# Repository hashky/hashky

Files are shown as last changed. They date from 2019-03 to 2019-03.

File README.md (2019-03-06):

This is the official repo of the Hashky. It contains everything required to construct a Hashky. 

The Hashky is an open source hardware authentication token and cryptocurrency wallet-seed generator.  It is a stand-alone device, host agnostic.   

Detailed instructions are in doc/manual.pdf. 

## LICENSE 
The Shalite library is a cut-down customize/improved fork of spaniakos/Cryptosuite under AGPL-3.0 license. Forked April 2018. 

The SHA204 library is licensed by Apache V2.0 license.

The rest is MIT license as stated in LICENSE.

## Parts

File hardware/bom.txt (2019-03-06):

5x 2 prong SMT tact switches TS-1236
1x atmel atsha204, SOT23 form factor
1x resistor 0805 4.7kohm-10kohm
1x hashky hat board(included in this git)
1x arduino CJMCU-beetle style board.(there is a similar board with a different pinout but same form factor, see manual)

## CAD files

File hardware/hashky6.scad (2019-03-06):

thick = 1;
length = 21.2;
width = 19.5;
height = 8;
slength = 6;
swidth = 7.5;
usb = 12;

/*u clamp thing*/
difference(){
union(){
difference(){
cube([length+2*thick,width+2*thick,height+2*thick]);
translate([ thick,thick,thick]) cube([length,width,height+thick]);
translate([ (length+2*thick-usb)/2,thick,thick]) cube([usb,width+thick,height*0.75]);
translate([0,-thick,thick*4.2]) cube([thick,thick*5,height/3]);
translate([0,width-thick*4,thick*4.2]) cube([thick,thick*6,height/3]);
}
/*translate([ thick,width-swidth+2*thick,height+thick]) cube([slength+thick,swidth,thick]);*/


translate([ length/2+thick,-0,0]) 

difference(){
scale([1.8,0.9,1]) difference(){
cylinder(height+2*thick,6,6);
cylinder(height+2*thick,4,4);
}
translate([-length,0,0])cube([2*length,width,height+2*thick]);

}
}

translate([thick,0,height+thick]) cube([length,thick,height/5]);
translate([length/4-4.7,width/2+2,0]) scale([0.34,0.34,0.34]) linear_extrude(5) rotate([180,0,0]) text("HASHKY",font = "Boulder:style=Bold");
translate([6.17,9.98,0]) cylinder(height+2*thick,1,1);
}

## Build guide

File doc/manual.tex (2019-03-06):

\documentclass{article}
\usepackage{hyperref}
\usepackage{graphicx}
\usepackage[font=small,labelfont=bf]{caption}
\begin{document}

\title{Manual on construction and use of the Hashky}
\author{Hashky \href{mailto:hashkyinfo@gmail.com}{hashkyinfo@gmail.com}}
\maketitle

\begin{abstract}
This document is to provide description, instructions and philosophy of use of the Hashky. 

\end{abstract}

\section{Motivation}

Password strength is the most important element of maintaining effective security practices. A strong password must be far removed from the human lexicon, which is a property that will make it difficult to remember. Compounding this issue is the suggested practice of changing passwords often. Another property of a strong password is raw entropy content, which manifests itself as long length. This makes typing them time consuming and prone to error. All of these factors make strong passwords inconvenient for the average user.

The Hashky is a platform agnostic piece of hardware designed to overcome these problems. It generates and stores secure authentication entropy in an IC which contains a hardware random number generator and a secure EEPROM. The entropy is easily accessed using a small amount of user supplied entropy(a pin code), and presented using USB keyboard emulation.  

The original use case was for situations which requiring passwords with high entropy in situations where software password managers are not available. A prime case is an encrypted volume at boot; or a bios password. As early development progressed, it became apparent that such a device would be useful for the secure generation and storage of seed entropy for cryptocurrency wallets.  

In order to further increase security, the project was open-sourced, so that the code could be audited to avoid the threat of manufacturer or developer perpetrated compromise.  

\section{Features}

The Hashky is capable of generating three different styles of alphanumeric secrets and passwords. The formats are as follows: BIP39 pneumonic seedphrase, generic short alphanumeric password, IOTA wallet seeds. The generic short format is alphanumeric, lower and uppercase, as well as some special characters selected for maximum compatibility. 

The other formats are open standards and should be referenced in their respective white papers \cite{bip39,iota}. The BIP39 seedphrase is supported by many cryptocurrency wallets of various projects as a wallet recovery function.  

\begin{figure}
\centering
 \captionsetup{width=.7\linewidth}

\caption{The Hashky incarnate, components labeled. The indicator LED is between the two boards, and can be witnessed through the gap labeled above. }
\label{fig:key}
\end{figure}

There are five buttons on the Hashky, labeled in Figure ~\ref{fig:key}. Buttons 1-4 are used for both input of user entropy and selection of password format. The fifth button labeled ENTER is used to mark the end of the sequence and initiate input of the password/secret. 

There is a secure element on the board, which is used to generate and securely store the entropy from which passwords are generated. The secure element contains a hardware random number generator and secure EEPROM that is resistant to physical tampering. For more details, refer to official datasheet of the Atmel ATSHA204. 

This device also has the function of the SHA256 hashing algorithm. The device can access the entropy for hashing, but is configured to preclude reading in plain text. This makes copying a configured Hashky impossible without physically compromising the advanced physical security features of the ATSHA204. 

The generic short format uses a set of $70$ characters and is of length $15$. This makes the entropy of this format $\log_2(70^{15})$, roughly $91$ bits. The code can easily be modified to use more characters. Some special characters are excluded in an effort to give maximum compatibility. It can be easily customised to the user's need without significantly changing the firmware.

\section{Features and use}

When buttons 1-4 have been actuated simultaneously, the device's indicator light will illuminate solid for a few seconds. This indicates that new personal entropy has been generated on the ATSHA204 and written to its EEPROM. Now your device contains your own personal unique entropy, and secrets generated are not dependent on any information known to any external entity. This can be done as many times as you like, but beware, there is no way to recover the state of the device after such a reset. The device must be powered up for this to work, so it will not happen in your pocket. 

Now, to generate/access passwords, the user begins by choosing the output format desired. This is done by pressing one of buttons 1-4. The corresponding formats for each button are:

\begin{enumerate}
\item  BIP39 pneumonic seedphrase \cite{bip39}
\item  BIP39 pneumonic seedphrase \cite{bip39}
\item  Generic 15 character alphanumeric and special character password
\item  IOTA wallet seeds \cite{iota}
\end{enumerate}

Following this selection, the user may input an arbitrary length base 4 sequence that can be thought of as a pin code or and address to each secret. The LED indicator will give a response during each actuation. Also buttons can be held down and actuations counted by observing the activity of the indicator LED(to allow reproducibility). After the desired sequence is entered, the ENTER button is pressed to finish the process and type the password into the host through USB keyboard emulation. This also resets the ephemeral state of the device, so that the same output will be achieved if we return to the output format selection step and reproduce the same sequence of button presses.

The default output is BIP39, so if the user simply hits enter without actuating buttons 1-4, a BIP39 output will be produced. 

The pin code itself should be thought of as a password and entropy. The first element of the code selecting the output format. 

\subsection{Philosophy of use}

The Hashky is a novel secure way to generate cryptocurrency wallets. It is very small(in physical size and memory) which makes it a bad candidate to carry malicious code. It is also open source and has a small codebase, so it can be easily audited. It is also fully deniable, as any input(pin code) to the device will produce a valid seed, so it is an excellent means of transportation for valuable seeds. The device also has no radios nor the capability to call home in any capacity. The connection being a purely physical one there is little chance of a MiTM attack, unless the host device is already compromised in some manner. 

In order to compromise a secret generated by the device, one must physically access your particular device and the relevant pin codes to access your secrets/passwords. If the device is stolen or otherwise placed in the attackers control, the key space is reduced but can only be accessed by entering pin codes into the device, unless the secure element is physically compromised in a hardware attack against the secure EEPROM. The pin codes are of arbitrary length, so in theory one may carry/generate a countably infinite number of passwords/wallet seeds with one Hashky.

Important secrets that are non-recoverable must be backed up by the user in a secure manner. It is the user's responsibility to guarantee that they will not be lost. 

The Hashky is only as secure as the device it is plugged into, you are still subject to keyloggers in a compromised host. 

\subsection{Good practices and tips}

\begin{itemize}
\item Use a USB extension cord to avoid damage to host USB ports when actuating tact switches.
\item Functionality on a tablet or phone is possible using an OTG adapter.
\item For extra security in the case that the device is stolen or lost, use a long pin code.
\item To use very long pin codes, hold buttons down and count the number of actuations by observing the LED response.
\item For use cases where the password can not be recovered, back it up by writing it down or printing it out and store it securely.
\item Remember it is only as secure as what you plug it into. This does not protect against keyloggers. 
\end{itemize} 

\section{Construction and initialization}

Physical construction of the Hashky is straight forward. Obtain all components on the bill of materials, including the Hashky "hat" PCB. Complete the PCB with the buttons and secure element. Now solder the hat PCB on top of the CJMCU beetle board with the pins. They will extend vertically, and must be trimmed after soldering. If you wish to use an ISP programmer for the firmware, you must leave them untrimmed until you have uploaded the firmware and tested the functionality. 

Once the Hashky has been physically constructed, the firmware must be uploaded. 

This is a two stage process. The first firmware is programmed to the device with either an ISP programmer or using the USB interface with the arduino bootloader. This firmware is called "init\_SHA". It contains routines which configure the secure element. This is a one-time process. After burning this firmware the device will be configured a few seconds after power-up and confirm this by emulating a USB keyboard and typing a confirmation text. This is very important for security as if the secure element is not properly configured, it will not make use of its secure features. 

In the main firmware "hashky\_firmware" there is a constant used to initialize the hashing process called "chal" on line 2326. It is not necessary, but good practice, to write some of your own entropy into this variable by changing around the hex digits.  Do not change the length of this variable. 

The firmware requires the two libraries in the firmware/libraries folder, so make them available to your arduino environment. 

The version of arduino used was 1.0.5+dfsg2-4. Some newer versions have serious bugs in parsing engine that will manifest in failure to compile the Hashky firmware. 

The main firmware is then written using either the USB interface with the arduino firmware or an ISP programmer. It is recommended to overwrite the arduino bootloader so that the device can not be accidentally reprogrammed during use. After the main firmware is written, the device is ready. 

The option of programming it over the USB interface using the arduino bootloader has been left for convenience and experimentation. 

The device can be re-initialized at any time by holding down keys 1-4 while the device is powered up. Upon success the LED will go solid then blink several times. This means new entropy has been written to the device. Remember this will overwrite any existing entropy so must be done with caution.

\subsection{Bill of materials}
\begin{itemize}
\item 5x 2 prong SMT tact switches TS-1236
\item 1x atmel atsha204, SOT23 form factor
\item 1x resistor 0805 4.7kohm-10kohm
\item 1x hashky hat board(included in this git)
\item 1x arduino CJMCU-beetle style board. Atmel Atmega32u4 or equivalent. Beware, there exists a board in this form factor with a different pinout. \ref{fig:cjmcu}
\end{itemize}

\begin{figure}
\centering
 \captionsetup{width=.7\linewidth}

\caption{An image of the development board from the BOM. CJMCU-beetle, an Atmel Atmega32u4. }
\label{fig:cjmcu}
\end{figure}

\subsection{Troubleshooting}

If the secure element is not properly connected, it will return all 0s, so the outputs for IOTA seeds and standard passwords will be a string of As. The BIP39 output will be similar, an output containing only the word "ambient". 

The 3D printed case is attached by sliding the male USB region of the device into the opening on the side of the case, so that the entire board is diagonal to the bottom of the case. Then the side opposite to the USB is pushed down, snapping the board down into the case. The case is often very difficult to remove non-destructively after this has been done. The case can physically obstruct the insertion of the Hashky into some USB host ports enough to prevent connection of the data lines. This can be remedied with a USB extension cord. 

It is highly advisable to use a USB extension cord. This avoids causing damage as well as a temporary disconnect of the device during actuation of tact switches. This temporary disconnect can power cycle the device, causing a reset of the ephemeral state of the device, which will confound the pin code sequence being entered(but not damage the device or effect the secure element). 

\begin{thebibliography}{99}
\bibitem{bip39} BIP39 \href{https://github.com/bitcoin/bips/blob/master/bip-0039.mediawiki}{https://github.com/bitcoin/bips/blob/master/bip-0039.mediawiki}
\bibitem{iota} IOTA SUPPORT: Creating a new Seed/Wallet  \href{https://iotasupport.com/gui-newseed.shtml}{https://iotasupport.com/gui-newseed.shtml}
\end{thebibliography}

\end{document}

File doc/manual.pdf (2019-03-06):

## Manual on construction and use of the Hashky

Hashky hashkyinfo@gmail.com

March 6, 2019

Abstract
This document is to provide description, instructions and philosophy of use of the Hashky.

## 1 Motivation

Password strength is the most important element of maintaining effective security practices. A strong password must be far removed from the human lexicon, which is a property that will make it difficult to remember. Compounding this issue is the suggested practice of changing passwords often. Another property of a strong password is raw entropy content, which manifests itself as long length. This makes typing them time consuming and prone to error. All of these factors make strong passwords inconvenient for the average user.
The Hashky is a platform agnostic piece of hardware designed to overcome these problems. It generates and stores secure authentication entropy in an IC which contains a hardware random number generator and a secure EEPROM. The entropy is easily accessed using a small amount of user supplied entropy(a pin code), and presented using USB keyboard emulation.
The original use case was for situations which requiring passwords with high entropy in situations where software password managers are not available. A prime case is an encrypted volume at boot; or a bios password. As early development progressed, it became apparent that such a device would be useful for the secure generation and storage of seed entropy for cryptocurrency wallets. In order to further increase security, the project was open-sourced, so that the code could be audited to avoid the threat of manufacturer or developer perpetrated compromise.

## 2 Features

The Hashky is capable of generating three different styles of alphanumeric secrets and passwords. The formats are as follows: BIP39 pneumonic seedphrase, generic short alphanumeric password, IOTA wallet seeds. The generic short format is alphanumeric, lower and uppercase, as well as some special characters selected for maximum compatibility.

1

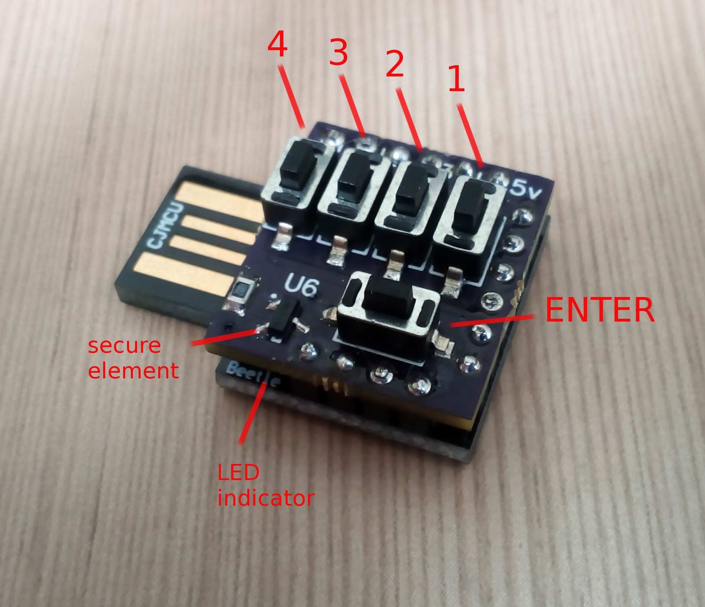
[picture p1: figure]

Figure 1: The Hashky incarnate, components labeled. The indicator LED is between the two boards, and can be witnessed through the gap labeled above.

The other formats are open standards and should be referenced in their respective white papers [1, 2]. The BIP39 seedphrase is supported by many cryptocurrency wallets of various projects as a wallet recovery function.
There are five buttons on the Hashky, labeled in Figure 1. Buttons 1-4 are used for both input of user entropy and selection of password format. The fifth button labeled ENTER is used to mark the end of the sequence and initiate input of the password/secret.
There is a secure element on the board, which is used to generate and securely store the entropy from which passwords are generated. The secure element contains a hardware random number generator and secure EEPROM that is resistant to physical tampering. For more details, refer to official datasheet of the Atmel ATSHA204.
This device also has the function of the SHA256 hashing algorithm. The device can access the entropy for hashing, but is configured to preclude reading in plain text. This makes copying a configured Hashky impossible without physically compromising the advanced physical security features of the ATSHA204. The generic short format uses a set of 70 characters and is of length 15. This makes the entropy of this format log2

(70¹⁵), roughly 91 bits. The code can easily be modified to use more characters. Some special characters are excluded in an effort to give maximum compatibility. It can be easily customised to the user’s need without significantly changing the firmware.

## 3 Features and use

When buttons 1-4 have been actuated simultaneously, the device’s indicator light will illuminate solid for a few seconds. This indicates that new personal entropy has been generated on the ATSHA204 and written to its EEPROM. Now

2

your device contains your own personal unique entropy, and secrets generated are not dependent on any information known to any external entity. This can be done as many times as you like, but beware, there is no way to recover the state of the device after such a reset. The device must be powered up for this to work, so it will not happen in your pocket.
Now, to generate/access passwords, the user begins by choosing the output format desired. This is done by pressing one of buttons 1-4. The corresponding formats for each button are:

### 1. BIP39 pneumonic seedphrase [1]

### 2. BIP39 pneumonic seedphrase [1]

### 3. Generic 15 character alphanumeric and special character password

### 4. IOTA wallet seeds [2]

Following this selection, the user may input an arbitrary length base 4 sequence that can be thought of as a pin code or and address to each secret. The LED indicator will give a response during each actuation. Also buttons can be held down and actuations counted by observing the activity of the indicator LED(to allow reproducibility). After the desired sequence is entered, the ENTER button is pressed to finish the process and type the password into the host through USB keyboard emulation. This also resets the ephemeral state of the device, so that the same output will be achieved if we return to the output format selection step and reproduce the same sequence of button presses.
The default output is BIP39, so if the user simply hits enter without actuating buttons 1-4, a BIP39 output will be produced.
The pin code itself should be thought of as a password and entropy. The first element of the code selecting the output format.

### 3.1 Philosophy of use

The Hashky is a novel secure way to generate cryptocurrency wallets. It is very small(in physical size and memory) which makes it a bad candidate to carry malicious code. It is also open source and has a small codebase, so it can be easily audited. It is also fully deniable, as any input(pin code) to the device will produce a valid seed, so it is an excellent means of transportation for valuable seeds. The device also has no radios nor the capability to call home in any capacity. The connection being a purely physical one there is little chance of a MiTM attack, unless the host device is already compromised in some manner. In order to compromise a secret generated by the device, one must physically access your particular device and the relevant pin codes to access your secrets/passwords. If the device is stolen or otherwise placed in the attackers control, the key space is reduced but can only be accessed by entering pin codes into the device, unless the secure element is physically compromised in a hardware attack against the secure EEPROM. The pin codes are of arbitrary

3

length, so in theory one may carry/generate a countably infinite number of passwords/wallet seeds with one Hashky.
Important secrets that are non-recoverable must be backed up by the user in a secure manner. It is the user’s responsibility to guarantee that they will not be lost.
The Hashky is only as secure as the device it is plugged into, you are still subject to keyloggers in a compromised host.

### 3.2 Good practices and tips

- Use a USB extension cord to avoid damage to host USB ports when actuating tact switches.
- Functionality on a tablet or phone is possible using an OTG adapter.
- For extra security in the case that the device is stolen or lost, use a long pin code.
- To use very long pin codes, hold buttons down and count the number of actuations by observing the LED response.
- For use cases where the password can not be recovered, back it up by writing it down or printing it out and store it securely.
- Remember it is only as secure as what you plug it into. This does not protect against keyloggers.

## 4 Construction and initialization

Physical construction of the Hashky is straight forward. Obtain all components on the bill of materials, including the Hashky ”hat” PCB. Complete the PCB with the buttons and secure element. Now solder the hat PCB on top of the CJMCU beetle board with the pins. They will extend vertically, and must be trimmed after soldering. If you wish to use an ISP programmer for the firmware, you must leave them untrimmed until you have uploaded the firmware and tested the functionality.
Once the Hashky has been physically constructed, the firmware must be uploaded.
This is a two stage process. The first firmware is programmed to the device with either an ISP programmer or using the USB interface with the arduino bootloader. This firmware is called ”init SHA”. It contains routines which configure the secure element. This is a one-time process. After burning this firmware the device will be configured a few seconds after power-up and confirm this by emulating a USB keyboard and typing a confirmation text. This is very important for security as if the secure element is not properly configured, it will not make use of its secure features.

4

In the main firmware ”hashky firmware” there is a constant used to initialize the hashing process called ”chal” on line 2326. It is not necessary, but good practice, to write some of your own entropy into this variable by changing around the hex digits. Do not change the length of this variable.
The firmware requires the two libraries in the firmware/libraries folder, so make them available to your arduino environment.
The version of arduino used was 1.0.5+dfsg2-4. Some newer versions have serious bugs in parsing engine that will manifest in failure to compile the Hashky firmware.
The main firmware is then written using either the USB interface with the arduino firmware or an ISP programmer. It is recommended to overwrite the arduino bootloader so that the device can not be accidentally reprogrammed during use. After the main firmware is written, the device is ready.
The option of programming it over the USB interface using the arduino bootloader has been left for convenience and experimentation.
The device can be re-initialized at any time by holding down keys 1-4 while the device is powered up. Upon success the LED will go solid then blink several times. This means new entropy has been written to the device. Remember this will overwrite any existing entropy so must be done with caution.

### 4.1 Bill of materials

- 5x 2 prong SMT tact switches TS-1236
- 1x atmel atsha204, SOT23 form factor
- 1x resistor 0805 4.7kohm-10kohm
- 1x hashky hat board(included in this git)
- 1x arduino CJMCU-beetle style board. Atmel Atmega32u4 or equivalent. Beware, there exists a board in this form factor with a different pinout. 2

### 4.2 Troubleshooting

If the secure element is not properly connected, it will return all 0s, so the outputs for IOTA seeds and standard passwords will be a string of As. The BIP39 output will be similar, an output containing only the word ”ambient”. The 3D printed case is attached by sliding the male USB region of the device into the opening on the side of the case, so that the entire board is diagonal to the bottom of the case. Then the side opposite to the USB is pushed down, snapping the board down into the case. The case is often very difficult to remove non-destructively after this has been done. The case can physically obstruct the insertion of the Hashky into some USB host ports enough to prevent connection of the data lines. This can be remedied with a USB extension cord.
It is highly advisable to use a USB extension cord. This avoids causing damage as well as a temporary disconnect of the device during actuation of tact

5

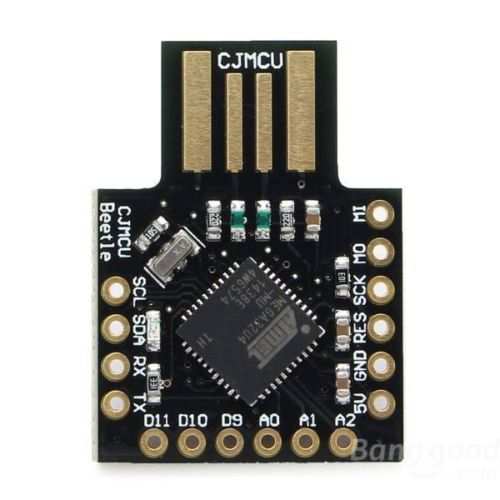
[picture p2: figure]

Figure 2: An image of the development board from the BOM. CJMCU-beetle, an Atmel Atmega32u4.

switches. This temporary disconnect can power cycle the device, causing a reset of the ephemeral state of the device, which will confound the pin code sequence being entered(but not damage the device or effect the secure element).

## References

[1] BIP39 https://github.com/bitcoin/bips/blob/master/bip-0039.mediawiki
[2] IOTA | SUPPORT: | Creating | a | new | Seed/Wallet
https://iotasupport.com/gui-newseed.shtml

6

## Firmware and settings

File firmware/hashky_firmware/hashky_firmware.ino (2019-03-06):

#include "sha256_lite.h" //sha lib for checksum
#include <avr/pgmspace.h>
#include <SHA204SWI.h>
#include <SHA204Definitions.h>

SHA204SWI sha204;

const char string_0[] PROGMEM ="abandon";
const char string_1[] PROGMEM ="ability";
const char string_2[] PROGMEM ="able";
const char string_3[] PROGMEM ="about";
const char string_4[] PROGMEM ="above";
const char string_5[] PROGMEM ="absent";
const char string_6[] PROGMEM ="absorb";
const char string_7[] PROGMEM ="abstract";
const char string_8[] PROGMEM ="absurd";
const char string_9[] PROGMEM ="abuse";
const char string_10[] PROGMEM ="access";
const char string_11[] PROGMEM ="accident";
const char string_12[] PROGMEM ="account";
const char string_13[] PROGMEM ="accuse";
const char string_14[] PROGMEM ="achieve";
const char string_15[] PROGMEM ="acid";
const char string_16[] PROGMEM ="acoustic";
const char string_17[] PROGMEM ="acquire";
const char string_18[] PROGMEM ="across";
const char string_19[] PROGMEM ="act";
const char string_20[] PROGMEM ="action";
const char string_21[] PROGMEM ="actor";
const char string_22[] PROGMEM ="actress";
const char string_23[] PROGMEM ="actual";
const char string_24[] PROGMEM ="adapt";
const char string_25[] PROGMEM ="add";
const char string_26[] PROGMEM ="addict";
const char string_27[] PROGMEM ="address";
const char string_28[] PROGMEM ="adjust";
const char string_29[] PROGMEM ="admit";
const char string_30[] PROGMEM ="adult";
const char string_31[] PROGMEM ="advance";
const char string_32[] PROGMEM ="advice";
const char string_33[] PROGMEM ="aerobic";
const char string_34[] PROGMEM ="affair";
const char string_35[] PROGMEM ="afford";
const char string_36[] PROGMEM ="afraid";
const char string_37[] PROGMEM ="again";
const char string_38[] PROGMEM ="age";
const char string_39[] PROGMEM ="agent";
const char string_40[] PROGMEM ="agree";
const char string_41[] PROGMEM ="ahead";
const char string_42[] PROGMEM ="aim";
const char string_43[] PROGMEM ="air";
const char string_44[] PROGMEM ="airport";
const char string_45[] PROGMEM ="aisle";
const char string_46[] PROGMEM ="alarm";
const char string_47[] PROGMEM ="album";
const char string_48[] PROGMEM ="alcohol";
const char string_49[] PROGMEM ="alert";
const char string_50[] PROGMEM ="alien";
const char string_51[] PROGMEM ="all";
const char string_52[] PROGMEM ="alley";
const char string_53[] PROGMEM ="allow";
const char string_54[] PROGMEM ="almost";
const char string_55[] PROGMEM ="alone";
const char string_56[] PROGMEM ="alpha";
const char string_57[] PROGMEM ="already";
const char string_58[] PROGMEM ="also";
const char string_59[] PROGMEM ="alter";
const char string_60[] PROGMEM ="always";
const char string_61[] PROGMEM ="amateur";
const char string_62[] PROGMEM ="amazing";
const char string_63[] PROGMEM ="among";
const char string_64[] PROGMEM ="amount";
const char string_65[] PROGMEM ="amused";
const char string_66[] PROGMEM ="analyst";
const char string_67[] PROGMEM ="anchor";
const char string_68[] PROGMEM ="ancient";
const char string_69[] PROGMEM ="anger";
const char string_70[] PROGMEM ="angle";
const char string_71[] PROGMEM ="angry";
const char string_72[] PROGMEM ="animal";
const char string_73[] PROGMEM ="ankle";
const char string_74[] PROGMEM ="announce";
const char string_75[] PROGMEM ="annual";
const char string_76[] PROGMEM ="another";
const char string_77[] PROGMEM ="answer";
const char string_78[] PROGMEM ="antenna";
const char string_79[] PROGMEM ="antique";
const char string_80[] PROGMEM ="anxiety";
const char string_81[] PROGMEM ="any";
const char string_82[] PROGMEM ="apart";
const char string_83[] PROGMEM ="apology";
const char string_84[] PROGMEM ="appear";
const char string_85[] PROGMEM ="apple";
const char string_86[] PROGMEM ="approve";
const char string_87[] PROGMEM ="april";
const char string_88[] PROGMEM ="arch";
const char string_89[] PROGMEM ="arctic";
const char string_90[] PROGMEM ="area";
const char string_91[] PROGMEM ="arena";
const char string_92[] PROGMEM ="argue";
const char string_93[] PROGMEM ="arm";
const char string_94[] PROGMEM ="armed";
const char string_95[] PROGMEM ="armor";
const char string_96[] PROGMEM ="army";
const char string_97[] PROGMEM ="around";
const char string_98[] PROGMEM ="arrange";
const char string_99[] PROGMEM ="arrest";
const char string_100[] PROGMEM ="arrive";
const char string_101[] PROGMEM ="arrow";
const char string_102[] PROGMEM ="art";
const char string_103[] PROGMEM ="artefact";
const char string_104[] PROGMEM ="artist";
const char string_105[] PROGMEM ="artwork";
const char string_106[] PROGMEM ="ask";
const char string_107[] PROGMEM ="aspect";
const char string_108[] PROGMEM ="assault";
const char string_109[] PROGMEM ="asset";
const char string_110[] PROGMEM ="assist";
const char string_111[] PROGMEM ="assume";
const char string_112[] PROGMEM ="asthma";
const char string_113[] PROGMEM ="athlete";
const char string_114[] PROGMEM ="atom";
const char string_115[] PROGMEM ="attack";
const char string_116[] PROGMEM ="attend";
const char string_117[] PROGMEM ="attitude";
const char string_118[] PROGMEM ="attract";
const char string_119[] PROGMEM ="auction";
const char string_120[] PROGMEM ="audit";
const char string_121[] PROGMEM ="august";
const char string_122[] PROGMEM ="aunt";
const char string_123[] PROGMEM ="author";
const char string_124[] PROGMEM ="auto";
const char string_125[] PROGMEM ="autumn";
const char string_126[] PROGMEM ="average";
const char string_127[] PROGMEM ="avocado";
const char string_128[] PROGMEM ="avoid";
const char string_129[] PROGMEM ="awake";
const char string_130[] PROGMEM ="aware";
const char string_131[] PROGMEM ="away";
const char string_132[] PROGMEM ="awesome";
const char string_133[] PROGMEM ="awful";
const char string_134[] PROGMEM ="awkward";
const char string_135[] PROGMEM ="axis";
const char string_136[] PROGMEM ="baby";
const char string_137[] PROGMEM ="bachelor";
const char string_138[] PROGMEM ="bacon";
const char string_139[] PROGMEM ="badge";
const char string_140[] PROGMEM ="bag";
const char string_141[] PROGMEM ="balance";
const char string_142[] PROGMEM ="balcony";
const char string_143[] PROGMEM ="ball";
const char string_144[] PROGMEM ="bamboo";
const char string_145[] PROGMEM ="banana";
const char string_146[] PROGMEM ="banner";
const char string_147[] PROGMEM ="bar";
const char string_148[] PROGMEM ="barely";
const char string_149[] PROGMEM ="bargain";
const char string_150[] PROGMEM ="barrel";
const char string_151[] PROGMEM ="base";
const char string_152[] PROGMEM ="basic";
const char string_153[] PROGMEM ="basket";
const char string_154[] PROGMEM ="battle";
const char string_155[] PROGMEM ="beach";
const char string_156[] PROGMEM ="bean";
const char string_157[] PROGMEM ="beauty";
const char string_158[] PROGMEM ="because";
const char string_159[] PROGMEM ="become";
const char string_160[] PROGMEM ="beef";
const char string_161[] PROGMEM ="before";
const char string_162[] PROGMEM ="begin";
const char string_163[] PROGMEM ="behave";
const char string_164[] PROGMEM ="behind";
const char string_165[] PROGMEM ="believe";
const char string_166[] PROGMEM ="below";
const char string_167[] PROGMEM ="belt";
const char string_168[] PROGMEM ="bench";
const char string_169[] PROGMEM ="benefit";
const char string_170[] PROGMEM ="best";
const char string_171[] PROGMEM ="betray";
const char string_172[] PROGMEM ="better";
const char string_173[] PROGMEM ="between";
const char string_174[] PROGMEM ="beyond";
const char string_175[] PROGMEM ="bicycle";
const char string_176[] PROGMEM ="bid";
const char string_177[] PROGMEM ="bike";
const char string_178[] PROGMEM ="bind";
const char string_179[] PROGMEM ="biology";
const char string_180[] PROGMEM ="bird";
const char string_181[] PROGMEM ="birth";
const char string_182[] PROGMEM ="bitter";
const char string_183[] PROGMEM ="black";
const char string_184[] PROGMEM ="blade";
const char string_185[] PROGMEM ="blame";
const char string_186[] PROGMEM ="blanket";
const char string_187[] PROGMEM ="blast";
const char string_188[] PROGMEM ="bleak";
const char string_189[] PROGMEM ="bless";
const char string_190[] PROGMEM ="blind";
const char string_191[] PROGMEM ="blood";
const char string_192[] PROGMEM ="blossom";
const char string_193[] PROGMEM ="blouse";
const char string_194[] PROGMEM ="blue";
const char string_195[] PROGMEM ="blur";
const char string_196[] PROGMEM ="blush";
const char string_197[] PROGMEM ="board";
const char string_198[] PROGMEM ="boat";
const char string_199[] PROGMEM ="body";
const char string_200[] PROGMEM ="boil";
const char string_201[] PROGMEM ="bomb";
const char string_202[] PROGMEM ="bone";
const char string_203[] PROGMEM ="bonus";
const char string_204[] PROGMEM ="book";
const char string_205[] PROGMEM ="boost";
const char string_206[] PROGMEM ="border";
const char string_207[] PROGMEM ="boring";
const char string_208[] PROGMEM ="borrow";
const char string_209[] PROGMEM ="boss";
const char string_210[] PROGMEM ="bottom";
const char string_211[] PROGMEM ="bounce";
const char string_212[] PROGMEM ="box";
const char string_213[] PROGMEM ="boy";
const char string_214[] PROGMEM ="bracket";
const char string_215[] PROGMEM ="brain";
const char string_216[] PROGMEM ="brand";
const char string_217[] PROGMEM ="brass";
const char string_218[] PROGMEM ="brave";
const char string_219[] PROGMEM ="bread";
const char string_220[] PROGMEM ="breeze";
const char string_221[] PROGMEM ="brick";
const char string_222[] PROGMEM ="bridge";
const char string_223[] PROGMEM ="brief";
const char string_224[] PROGMEM ="bright";
const char string_225[] PROGMEM ="bring";
const char string_226[] PROGMEM ="brisk";
const char string_227[] PROGMEM ="broccoli";
const char string_228[] PROGMEM ="broken";
const char string_229[] PROGMEM ="bronze";
const char string_230[] PROGMEM ="broom";
const char string_231[] PROGMEM ="brother";
const char string_232[] PROGMEM ="brown";
const char string_233[] PROGMEM ="brush";
const char string_234[] PROGMEM ="bubble";
const char string_235[] PROGMEM ="buddy";
const char string_236[] PROGMEM ="budget";
const char string_237[] PROGMEM ="buffalo";
const char string_238[] PROGMEM ="build";
const char string_239[] PROGMEM ="bulb";
const char string_240[] PROGMEM ="bulk";
const char string_241[] PROGMEM ="bullet";
const char string_242[] PROGMEM ="bundle";
const char string_243[] PROGMEM ="bunker";
const char string_244[] PROGMEM ="burden";
const char string_245[] PROGMEM ="burger";
const char string_246[] PROGMEM ="burst";
const char string_247[] PROGMEM ="bus";
const char string_248[] PROGMEM ="business";
const char string_249[] PROGMEM ="busy";
const char string_250[] PROGMEM ="butter";
const char string_251[] PROGMEM ="buyer";
const char string_252[] PROGMEM ="buzz";
const char string_253[] PROGMEM ="cabbage";
const char string_254[] PROGMEM ="cabin";
const char string_255[] PROGMEM ="cable";
const char string_256[] PROGMEM ="cactus";
const char string_257[] PROGMEM ="cage";
const char string_258[] PROGMEM ="cake";
const char string_259[] PROGMEM ="call";
const char string_260[] PROGMEM ="calm";
const char string_261[] PROGMEM ="camera";
const char string_262[] PROGMEM ="camp";
const char string_263[] PROGMEM ="can";
const char string_264[] PROGMEM ="canal";
const char string_265[] PROGMEM ="cancel";
const char string_266[] PROGMEM ="candy";
const char string_267[] PROGMEM ="cannon";
const char string_268[] PROGMEM ="canoe";
const char string_269[] PROGMEM ="canvas";
const char string_270[] PROGMEM ="canyon";
const char string_271[] PROGMEM ="capable";
const char string_272[] PROGMEM ="capital";
const char string_273[] PROGMEM ="captain";
const char string_274[] PROGMEM ="car";
const char string_275[] PROGMEM ="carbon";
const char string_276[] PROGMEM ="card";
const char string_277[] PROGMEM ="cargo";
const char string_278[] PROGMEM ="carpet";
const char string_279[] PROGMEM ="carry";
const char string_280[] PROGMEM ="cart";
const char string_281[] PROGMEM ="case";
const char string_282[] PROGMEM ="cash";
const char string_283[] PROGMEM ="casino";
const char string_284[] PROGMEM ="castle";
const char string_285[] PROGMEM ="casual";
const char string_286[] PROGMEM ="cat";
const char string_287[] PROGMEM ="catalog";
const char string_288[] PROGMEM ="catch";
const char string_289[] PROGMEM ="category";
const char string_290[] PROGMEM ="cattle";
const char string_291[] PROGMEM ="caught";
const char string_292[] PROGMEM ="cause";
const char string_293[] PROGMEM ="caution";
const char string_294[] PROGMEM ="cave";
const char string_295[] PROGMEM ="ceiling";
const char string_296[] PROGMEM ="celery";
const char string_297[] PROGMEM ="cement";
const char string_298[] PROGMEM ="census";
const char string_299[] PROGMEM ="century";
const char string_300[] PROGMEM ="cereal";
const char string_301[] PROGMEM ="certain";
const char string_302[] PROGMEM ="chair";
const char string_303[] PROGMEM ="chalk";
const char string_304[] PROGMEM ="champion";
const char string_305[] PROGMEM ="change";
const char string_306[] PROGMEM ="chaos";
const char string_307[] PROGMEM ="chapter";
const char string_308[] PROGMEM ="charge";
const char string_309[] PROGMEM ="chase";
const char string_310[] PROGMEM ="chat";
const char string_311[] PROGMEM ="cheap";
const char string_312[] PROGMEM ="check";
const char string_313[] PROGMEM ="cheese";
const char string_314[] PROGMEM ="chef";
const char string_315[] PROGMEM ="cherry";
const char string_316[] PROGMEM ="chest";
const char string_317[] PROGMEM ="chicken";
const char string_318[] PROGMEM ="chief";
const char string_319[] PROGMEM ="child";
const char string_320[] PROGMEM ="chimney";
const char string_321[] PROGMEM ="choice";
const char string_322[] PROGMEM ="choose";
const char string_323[] PROGMEM ="chronic";
const char string_324[] PROGMEM ="chuckle";
const char string_325[] PROGMEM ="chunk";
const char string_326[] PROGMEM ="churn";
const char string_327[] PROGMEM ="cigar";
const char string_328[] PROGMEM ="cinnamon";
const char string_329[] PROGMEM ="circle";
const char string_330[] PROGMEM ="citizen";
const char string_331[] PROGMEM ="city";
const char string_332[] PROGMEM ="civil";
const char string_333[] PROGMEM ="claim";
const char string_334[] PROGMEM ="clap";
const char string_335[] PROGMEM ="clarify";
const char string_336[] PROGMEM ="claw";
const char string_337[] PROGMEM ="clay";
const char string_338[] PROGMEM ="clean";
const char string_339[] PROGMEM ="clerk";
const char string_340[] PROGMEM ="clever";
const char string_341[] PROGMEM ="click";
const char string_342[] PROGMEM ="client";
const char string_343[] PROGMEM ="cliff";
const char string_344[] PROGMEM ="climb";
const char string_345[] PROGMEM ="clinic";
const char string_346[] PROGMEM ="clip";
const char string_347[] PROGMEM ="clock";
const char string_348[] PROGMEM ="clog";
const char string_349[] PROGMEM ="close";
const char string_350[] PROGMEM ="cloth";
const char string_351[] PROGMEM ="cloud";
const char string_352[] PROGMEM ="clown";
const char string_353[] PROGMEM ="club";
const char string_354[] PROGMEM ="clump";
const char string_355[] PROGMEM ="cluster";
const char string_356[] PROGMEM ="clutch";
const char string_357[] PROGMEM ="coach";
const char string_358[] PROGMEM ="coast";
const char string_359[] PROGMEM ="coconut";
const char string_360[] PROGMEM ="code";
const char string_361[] PROGMEM ="coffee";
const char string_362[] PROGMEM ="coil";
const char string_363[] PROGMEM ="coin";
const char string_364[] PROGMEM ="collect";
const char string_365[] PROGMEM ="color";
const char string_366[] PROGMEM ="column";
const char string_367[] PROGMEM ="combine";
const char string_368[] PROGMEM ="come";
const char string_369[] PROGMEM ="comfort";
const char string_370[] PROGMEM ="comic";
const char string_371[] PROGMEM ="common";
const char string_372[] PROGMEM ="company";
const char string_373[] PROGMEM ="concert";
const char string_374[] PROGMEM ="conduct";
const char string_375[] PROGMEM ="confirm";
const char string_376[] PROGMEM ="congress";
const char string_377[] PROGMEM ="connect";
const char string_378[] PROGMEM ="consider";
const char string_379[] PROGMEM ="control";
const char string_380[] PROGMEM ="convince";
const char string_381[] PROGMEM ="cook";
const char string_382[] PROGMEM ="cool";
const char string_383[] PROGMEM ="copper";
const char string_384[] PROGMEM ="copy";
const char string_385[] PROGMEM ="coral";
const char string_386[] PROGMEM ="core";
const char string_387[] PROGMEM ="corn";
const char string_388[] PROGMEM ="correct";
const char string_389[] PROGMEM ="cost";
const char string_390[] PROGMEM ="cotton";
const char string_391[] PROGMEM ="couch";
const char string_392[] PROGMEM ="country";
const char string_393[] PROGMEM ="couple";
const char string_394[] PROGMEM ="course";
const char string_395[] PROGMEM ="cousin";
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
void loop() {
  
  
 int buttonState1 = digitalRead(bPin1);
  if ((buttonState1 == LOW) && (previousButtonState1 != buttonState1)) {
    rollhash(0x0);
    previousButtonState1 = LOW;
    blinkk();
    first(1);
  }else{
  previousButtonState1 = HIGH;
  delay(delaytime);
  }
  
    int buttonState2 = digitalRead(bPin2);
  if ((buttonState2 == LOW) && (previousButtonState2 != buttonState2)) {
        rollhash(0x1);
    previousButtonState2 = LOW;
    blinkk();
    first(2);
  }else{
  previousButtonState2 = HIGH;
  delay(delaytime);
  }
  
    int buttonState3 = digitalRead(bPin3);
  if ((buttonState3 == LOW) && (previousButtonState3 != buttonState3)) {
    rollhash(0x2);
    previousButtonState3 = LOW;
    blinkk();
    first(3);
  }else{
  previousButtonState3 = HIGH;
  delay(delaytime);
  }
  
      int buttonState4 = digitalRead(bPin4);
  if ((buttonState4 == LOW) && (previousButtonState4 != buttonState4)) {
    rollhash(0x3);
    previousButtonState4 = LOW;
    blinkk();
    first(4);
  }else{
  previousButtonState4 = HIGH;
  delay(delaytime);
  }
  
  
  int buttonState5 = digitalRead(EnterPin);
  if ((buttonState5 == LOW) && (previousButtonState5 != buttonState5)) {
  rollhash(0x4);
  if (firstpin==1){
   mkiota();
  }else if(firstpin==2){
   mkpass();

  }else{
    mkbip39();
    
  }
  firstpin=0;
    memcpy(challenge, chal,MAC_CHALLENGE_SIZE );
      previousButtonState5 = LOW;
  }else{
  previousButtonState5 = HIGH;

  delay(delaytime);
  
  }


if ((buttonState1==LOW) && (buttonState2==LOW) && (buttonState3==LOW) && (buttonState4==LOW)){
    digitalWrite(led, HIGH);  
  delay(2000);              
  digitalWrite(led, LOW);   
  initkeys();
  blinkk();
  
}


}

void first(int k){
  if (firstpin==0){
    firstpin=k;
  }
}

void rollhash(uint8_t k){
  uint8_t ret_code = sha204.mac(&command[0], &response[0], 0, k, (uint8_t *) challenge);
  updatechal(response);
}


void mkpass(){
   rollhash(0x14);
 for (int j=0;j<15;j++){
   char out = (char) (challenge[j]%(123-48)+48);
   if ( (((int)out)==96) | ( (((int)out)>=58) & (((int)out)<=62) ) ){
     Keyboard.print( (char) 36);
   }else{
          Keyboard.print( out);
   }
 } 
  Keyboard.print("\n");
}


void mkiota(){
  for (int j=0;j<4;j++){
    rollhash(0x9+0x1*j);
       for (int i=2;i<MAC_CHALLENGE_SIZE-10;i++){
        int k = challenge[i]%27;
    
         Keyboard.print(getiota( k));

 }
  }
  Keyboard.print(getiota(challenge[MAC_CHALLENGE_SIZE-9]%27));
  Keyboard.print("\n");
}

char getiota(int k){
         char out;
          
        if (k==26){
          out = (char) 57;
        }else{
       out = (char) (k+65);
        }
        return out;
}

uint8_t shasum(uint8_t* dat){//[MAC_CHALLENGE_SIZE]){
  Sha256.init();
for (int d=0; d<MAC_CHALLENGE_SIZE;d++){
Sha256.print(  (char) dat[d]);
 }
//printarray(dat);
  uint8_t* b = Sha256.result();
  return b[0];
}


uint16_t catbytes(uint8_t b1, uint8_t b2, int k, int n){
  return ((b1^(b1>>k<<k))<<(11-k)) | (b2>>(8-n) << (11-k-n));
  //cat first last k bits to first n bits from the bytes respectively
}

void mkbip39(){
  rollhash(0x8);
 
  uint8_t data[MAC_CHALLENGE_SIZE+1];
 memcpy(data,challenge,MAC_CHALLENGE_SIZE );
  uint8_t sum = shasum(challenge) ;
  data[MAC_CHALLENGE_SIZE] = sum;
  
  
  
  uint16_t bip[24] ;
int kk=0;
for (int j=0;j<24;j++){
  bip[kk] = 0;
 int addy1 =  (11*j)/8;
 int addy1b = (11*j) % 8;
 int  addy2 = (11*(j+1))/8;
 int  addy2b = (11*(j+1))%8 - 1;
 if(addy2b==-1){
    addy2 = addy2 - 1;
    addy2b=7;
 }
 int dist = addy2 - addy1;
 if (dist == 1){
   bip[kk] = catbytes(data[addy1],data[addy2],8-addy1b,addy2b+1);
 }else if (dist==2){ //handle case where 3 bytes go to one 11bit long
     uint16_t bob = catbytes(data[addy1],data[addy2-1],8-addy1b,8);
     bip[kk] = bob | (data[addy2]>>(8-(addy2b+1))); //cat bob long to first addyb+1 bits of last byte
   }
 kk++;
}




for (int dd=0;dd<24;dd=dd+1){
if (dd==23){
    Keyboard.print(strcat(getbip(bip[dd]),"\n" ));
   }else{
   Keyboard.print(strcat(getbip(bip[dd])," ") );
   }
   delay(30);
}


}


void blinkk(){
  digitalWrite(led, HIGH);  
  delay(50);              
  digitalWrite(led, LOW);    
  delay(50);
  digitalWrite(led, HIGH);
  delay(50);
  digitalWrite(led, LOW);
  delay(50);              
}


void updatechal( uint8_t resp[MAC_RSP_SIZE]){
  for (int i=1;i<MAC_RSP_SIZE - 2;i++){
  challenge[i-1] = resp[i];
}//dont use the first few bytes because they are deterministic, a header. 
}



char* getbip(int j){
 strcpy_P(buffer, (char*)pgm_read_word(&(string_table[j])));
 return buffer;
  
}

byte derivekey(uint8_t n)
{
  uint8_t command[MAC_COUNT_LONG];
  uint8_t response[SHA204_RSP_SIZE_MAX];
  
    uint8_t ncommand[MAC_COUNT_LONG];
  
  uint8_t data[20];
  
  for (int j=0;j<20;j++){
   data[j] = j; 
  }
  
  uint8_t nresponse[SHA204_RSP_SIZE_MAX];
  
  uint8_t ret_non = sha204.nonce(&ncommand[0], &nresponse[0], 0, (uint8_t *) data);
  
  uint8_t ret_code = sha204.derive_key(&command[0], &response[0], 0, n, 0);

}

byte initkeys(){
  for (int j=0; j <= 15; j++){
          uint8_t slot = 0x01*j;
          derivekey(slot);
  }
  
}

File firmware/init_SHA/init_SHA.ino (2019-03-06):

#include <SHA204SWI.h>
#include <SHA204Definitions.h>

SHA204SWI sha204;
int go = 0;
int led=13;

void setup() {
  Keyboard.begin();
}

void loop() {
 if (go==0){ 
    digitalWrite(led, HIGH);
  delay(2000);
  digitalWrite(led, LOW);
    writeconfig();
  lockconfig();
  initkeys();
  lockdata();
  Keyboard.print("Chip configured, entropy written");
  go = 1;
 digitalWrite(led, HIGH);
  delay(500);
  digitalWrite(led, LOW);
 delay(500);
 digitalWrite(led, HIGH);
  delay(500);
  digitalWrite(led, LOW); 
 }
  delay(2000);
}




byte derivekey(uint8_t n)
{
  uint8_t command[MAC_COUNT_LONG];
  uint8_t response[SHA204_RSP_SIZE_MAX];
  
    uint8_t ncommand[MAC_COUNT_LONG];
  
  uint8_t data[20];
  
  for (int j=0;j<20;j++){
   data[j] = j; 
  }
  
  uint8_t nresponse[SHA204_RSP_SIZE_MAX];
  
  uint8_t ret_non = sha204.nonce(&ncommand[0], &nresponse[0], 0, (uint8_t *) data);
  
  uint8_t ret_code = sha204.derive_key(&command[0], &response[0], 0, n, 0);

}

byte initkeys(){
  for (int j=0; j <= 15; j++){
          uint8_t slot = 0x01*j;
          derivekey(slot);
  }
  
}

byte lockconfig(){
  uint8_t command[MAC_COUNT_LONG];
  uint8_t response[SHA204_RSP_SIZE_MAX];
  uint8_t ret_code = sha204.lock(&command[0], &response[0], 0x80, 0x0);
}

byte lockdata(){
  uint8_t command[MAC_COUNT_LONG];
  uint8_t response[SHA204_RSP_SIZE_MAX];
  uint8_t ret_code = sha204.lock(&command[0], &response[0], 0x81, 0x0);
}

byte writeconfig()
{
  uint8_t response[SHA204_RSP_SIZE_MAX];
 uint8_t command[MAC_COUNT_LONG];
for (int j=0; j < 8; j++){
  uint8_t data[4] = {0x80 + 2*j,0x30 + 2*j, 0x80 +2*j+1, 0x30 +2*j+1};
  uint16_t address = 0x00014 + 0x0004*j;
  uint8_t ret_code = sha204.write(&command[0], &response[0], 0x00, address,&data[0],&command[0]);/*hacky, command is jsut a placeholder, not used*/
  
  for (int i=1; i<5; i++)
  {
    Serial.print(response[i], HEX);
    Serial.print(' ');
  }
    Serial.println(j);

    
  
}
  
}
